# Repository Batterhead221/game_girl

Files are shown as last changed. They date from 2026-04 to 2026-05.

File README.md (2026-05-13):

# game_girl

GAME GIRL is a custom ESP32-S3 handheld mini-arcade built around a monochrome OLED display, rotary encoder controls, button input, buzzer audio, and battery support. AKA a handheld controlable tamagotchi like digital pet that I made for my niece.

## Features
- Custom PCB designed in KiCad
- ESP32-S3 based handheld platform
- 128x64 I2C OLED display
- Rotary encoder + push switch input
- Main action button
- Active buzzer audio
- Soft sleep mode
- Original mini-games:
  - Dress Up
  - Pocket Pet

## Hardware
- ESP32-S3 module
- 128x64 OLED
- Rotary encoder
- Pushbutton
- Active buzzer with transistor driver
- Single-cell LiPo support

## Firmware
The firmware is written in Arduino/C++ and organized as a menu-driven state machine. The device includes a launcher menu, game states, UI rendering, sound feedback, and long-press sleep behavior for handheld use.

## Engineering Highlights
- Built a complete handheld embedded system from schematic to assembled PCB
- Designed a compact display-based UI for limited-resolution hardware
- Implemented encoder and button-driven navigation across multiple games
- Added battery-friendly soft sleep behavior
- Debugged hardware bring-up issues including buzzer driver behavior and real-world encoder handling

## Challenges and Fixes
One of the main bring-up issues was the buzzer driver stage. The buzzer itself tested correctly, but in-circuit debugging showed the low-side transistor stage was not pulling the buzzer node low enough. After tracing the behavior with meter checks and signal testing, the emitter path was corrected to achieve proper switching. I also iterated on encoder handling to make gameplay and menu control more usable with a mechanical rotary input.

## Status
Working prototype. Core hardware and firmware are functional, with several improvements identified for a future board revision.

Next rev will be more compact, "kid friendly" and "prettier"

Designed & Engineered by Brandon Shelly

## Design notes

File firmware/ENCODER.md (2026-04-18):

#include <Wire.h>
#include <LiquidCrystal_I2C.h>

LiquidCrystal_I2C lcd(0x27, 16, 2);

const int ENC_A  = 1;   // D0
const int ENC_B  = 2;   // D1
const int ENC_SW = 3;   // D2

int count = 0;
int lastAState = HIGH;
unsigned long lastStepTime = 0;
const unsigned long stepDelayMs = 3;

void drawScreen() {
  lcd.clear();
  lcd.setCursor(0, 0);
  lcd.print("GAME_GIRL");
  lcd.setCursor(0, 1);
  lcd.print("COUNT: ");
  lcd.print(count);
}

void setup() {
  Wire.begin(5, 6);   // SDA=D4, SCL=D5
  lcd.init();
  lcd.backlight();

  pinMode(ENC_A, INPUT_PULLUP);
  pinMode(ENC_B, INPUT_PULLUP);
  pinMode(ENC_SW, INPUT_PULLUP);

  lastAState = digitalRead(ENC_A);
  drawScreen();
}

void loop() {
  int aState = digitalRead(ENC_A);

  if (aState != lastAState) {
    if (millis() - lastStepTime > stepDelayMs) {
      if (aState == LOW) {
        if (digitalRead(ENC_B) != aState) {
          count++;
        } else {
          count--;
        }
        drawScreen();
        lastStepTime = millis();
      }
    }
  }

  lastAState = aState;

  if (digitalRead(ENC_SW) == LOW) {
    lcd.clear();
    lcd.setCursor(0, 0);
    lcd.print("BUTTON PRESS");
    lcd.setCursor(0, 1);
    lcd.print("COUNT: ");
    lcd.print(count);
    delay(250);

    while (digitalRead(ENC_SW) == LOW) {
      delay(10);
    }

    drawScreen();
  }
}

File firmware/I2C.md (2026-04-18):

#include <Wire.h>

void setup() {
  Serial.begin(115200);
  delay(2000);

  Serial.println();
  Serial.println("BOOT OK");
  Serial.println("STARTING I2C SCAN");

  Wire.begin(5, 6);   // SDA=D4, SCL=D5 on XIAO ESP32S3
  delay(100);
}

void loop() {
  byte error, address;
  int count = 0;

  Serial.println("SCANNING...");

  for (address = 1; address < 127; address++) {
    Wire.beginTransmission(address);
    error = Wire.endTransmission();

    if (error == 0) {
      Serial.print("FOUND I2C DEVICE AT 0X");
      if (address < 16) Serial.print("0");
      Serial.println(address, HEX);
      count++;
    }
  }

  if (count == 0) {
    Serial.println("NO I2C DEVICES FOUND");
  } else {
    Serial.println("SCAN DONE");
  }

  Serial.println("-----");
  delay(3000);
}

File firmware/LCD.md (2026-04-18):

#include <Wire.h>
#include <LiquidCrystal_I2C.h>

LiquidCrystal_I2C lcd(0x27, 16, 2);

void setup() {
  Wire.begin(5, 6);   // SDA=D4, SCL=D5 on XIAO ESP32S3
  lcd.init();
  lcd.backlight();

  lcd.clear();
  lcd.setCursor(0, 0);
  lcd.print("GAME_GIRL");

  lcd.setCursor(0, 1);
  lcd.print("PRESS TO PLAY");
}

void loop() {
}

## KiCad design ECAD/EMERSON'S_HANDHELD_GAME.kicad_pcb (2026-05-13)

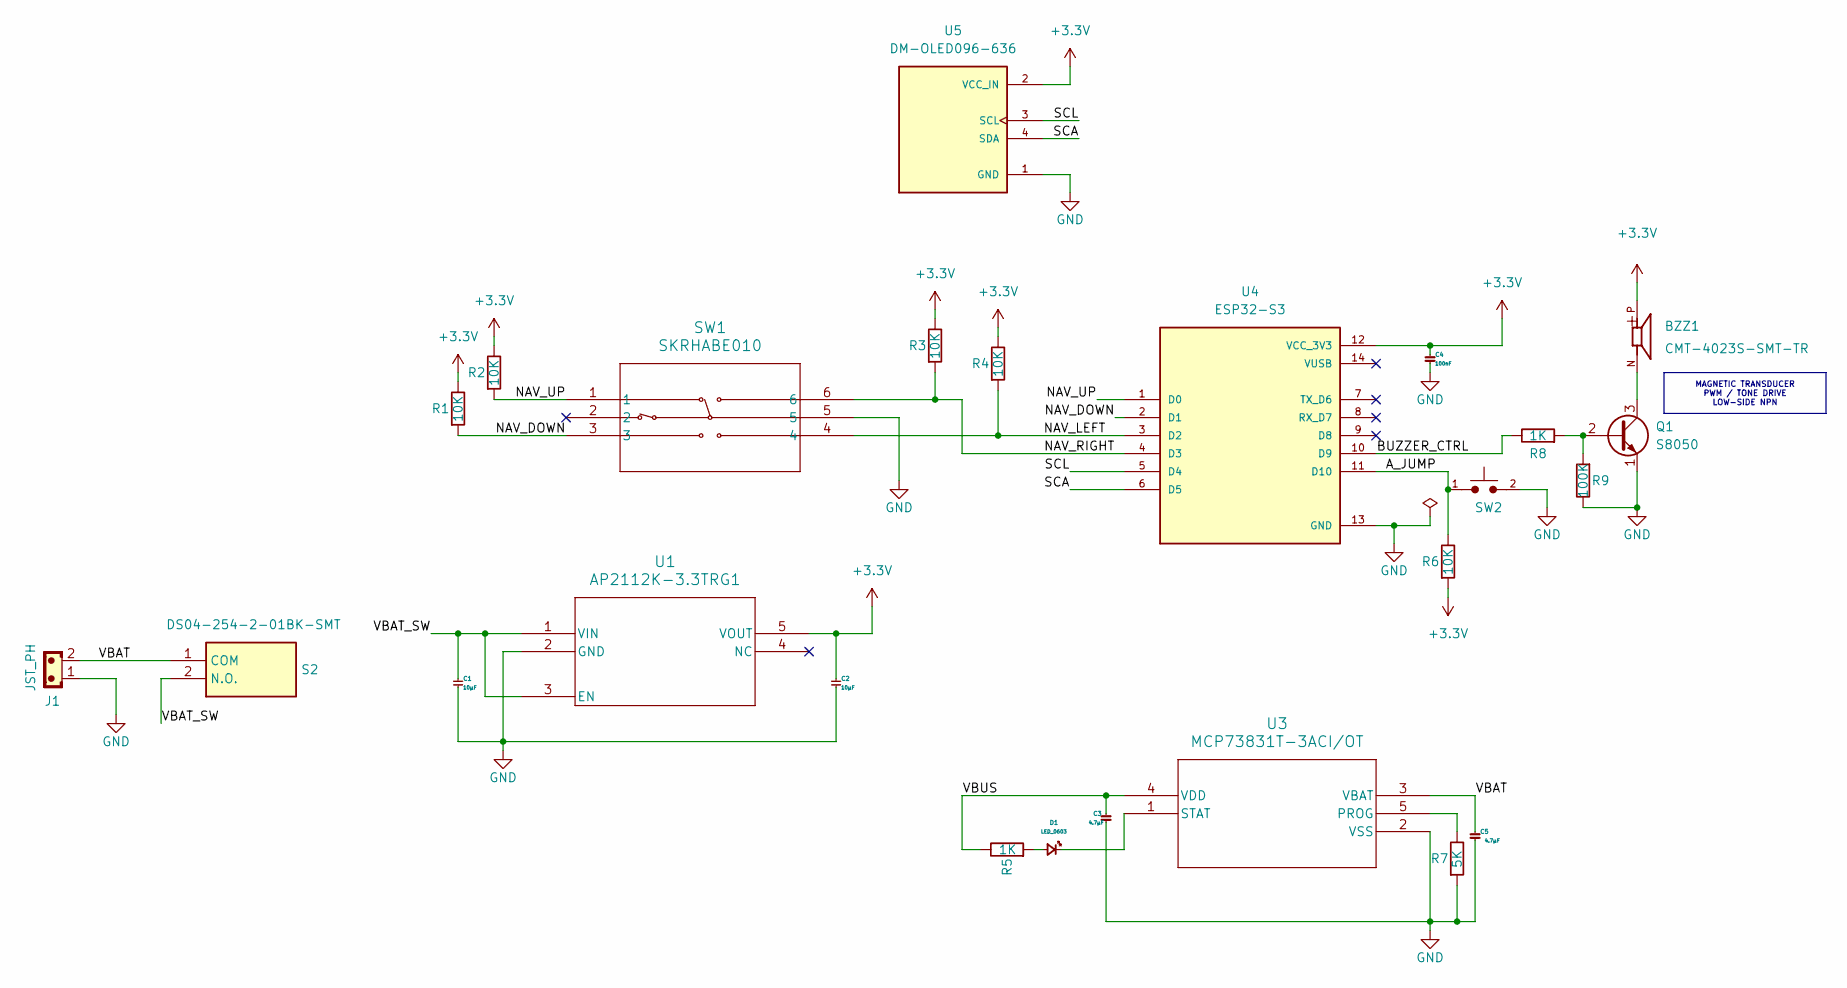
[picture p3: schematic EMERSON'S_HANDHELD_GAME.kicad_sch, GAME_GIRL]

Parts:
BZZ1: CMT-4023S-SMT-TR; CUI_CMT-4023S-SMT-TR; PARTREV 1.0
C1, C2: 10µF; C_0603_1608Metric
C3, C5: 4.7µF; C_0805_2012Metric; MPN C3216X5R1V226M160AC
C4: 100nF; C_0603_1608Metric
D1: LED_0603; LED_0603_1608Metric
J1: JST_PH; JST_PH_S2B-PH-K_1x02_P2.00mm_Horizontal
Q1: S8050; TO-92
R1, R2, R3, R4, R6: 10K; R_0603_1608Metric
R5, R8: 1K; R_0603_1608Metric
R7: 5K; R_0603_1608Metric
R9: 100K; R_0603_1608Metric
S2: DS04-254-2-01BK-SMT; Mouser Part Number 490-DS04254201BK-SMT
SW1: SKRHABE010
SW2: BUTTON; OMRON_SW_THT
U1: AP2112K-3.3TRG1; SOT-23-5
U3: MCP73831T-3ACI/OT; SOT-23-5_MC_MCH
U4: ESP32-S3; ESP32-S3_PADS_REMOVED; PARTREV 23/05/2022
U5: DM-OLED096-636; OLED; PARTREV 2018-09-10

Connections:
+3.3V: BZZ1.P, C2.2, C4.2, R1.2, R2.2, R3.2, R4.2, R6.1, U1.5 (VOUT), U4.12 (VCC_3V3), U5.2 (VCC_IN)
/A_JUMP: R6.2, SW2.1, U4.11 (D10)
/BUZZER_CTRL: R8.2, U4.10 (D9)
/NAV_DOWN: R1.1, SW1.3, U4.2 (D1)
/NAV_LEFT: R4.1, SW1.4, U4.3 (D2)
/NAV_RIGHT: R3.1, SW1.6, U4.4 (D3)
/NAV_UP: R2.1, SW1.1, U4.1 (D0)
/SCA: U4.6 (D5), U5.4 (SDA)
/SCL: U4.5 (D4), U5.3 (SCL)
/VBAT: C5.2, J1.2, S2.1 (COM), U3.3 (VBAT)
/VBAT_SW: C1.2, S2.2 (N.O.), U1.1 (VIN), U1.3 (EN)
/VBUS: C3.2, R5.2, U3.4 (VDD)
GND: C1.1, C2.1, C3.1, C4.1, C5.1, J1.1, Q1.1 (E), R7.1, R9.2, SW1.5, SW2.2, U1.2 (GND), U3.2 (VSS), U4.13 (GND), U5.1 (GND)
unnamed: D1.2 (A), R5.1
unnamed: D1.1 (K), U3.1 (STAT)
unnamed: Q1.2 (B), R8.1, R9.1
unnamed: BZZ1.N, Q1.3 (C)
unnamed: R7.2, U3.5 (PROG)

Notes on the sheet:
MAGNETIC TRANSDUCER PWM / TONE DRIVE LOW-SIDE NPN

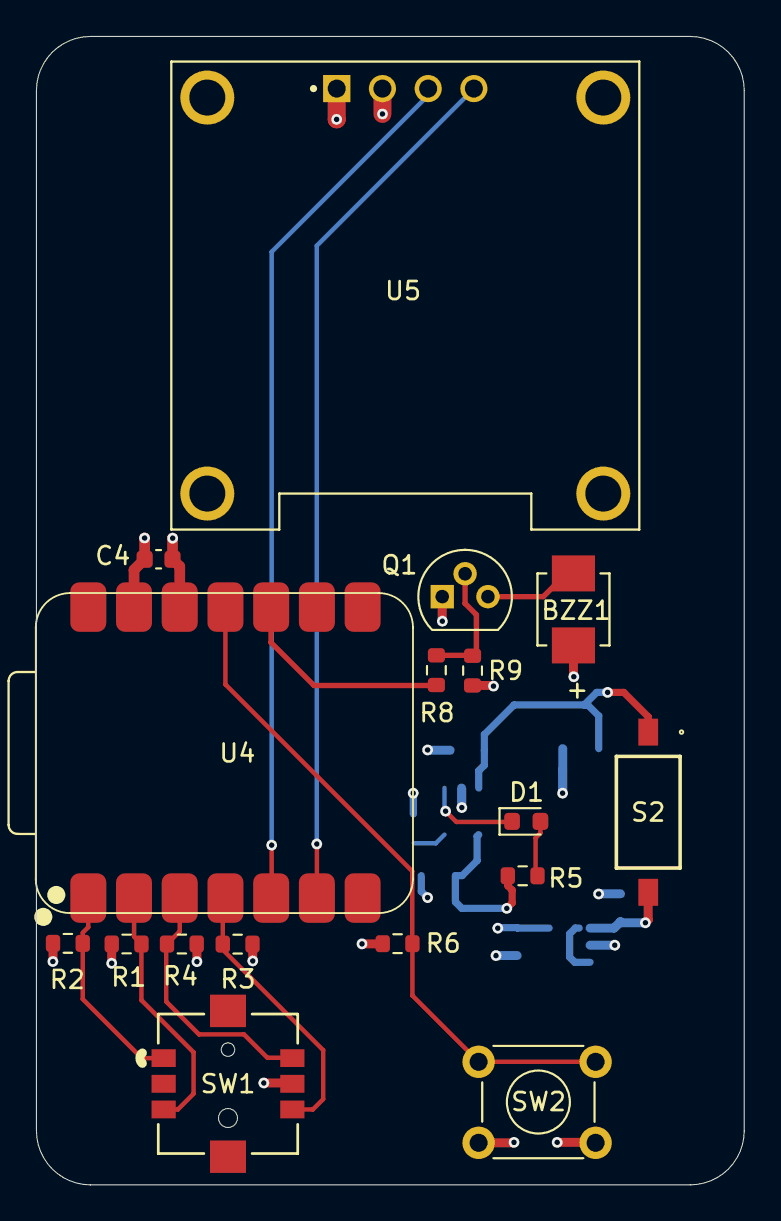
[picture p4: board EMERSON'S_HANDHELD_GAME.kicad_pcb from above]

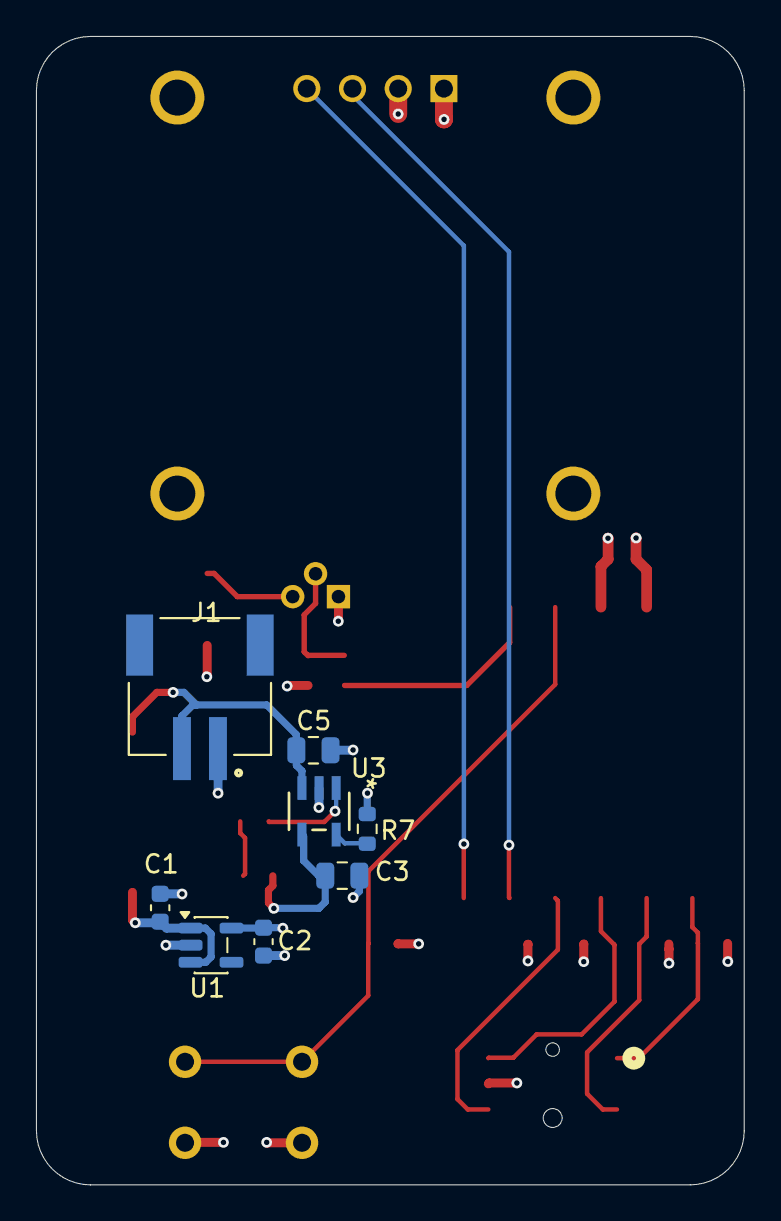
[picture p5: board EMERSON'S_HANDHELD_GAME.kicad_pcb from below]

Board: 4 copper layers, 39.3 x 63.8 mm, 25 parts (8 on the bottom side), 18 nets.

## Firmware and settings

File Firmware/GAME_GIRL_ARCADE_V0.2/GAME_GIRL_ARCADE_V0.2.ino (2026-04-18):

#include <Arduino.h>
#include <Wire.h>
#include <Adafruit_GFX.h>
#include <Adafruit_SSD1306.h>
#include "esp_sleep.h"

// ======================================================
// XIAO pin compatibility for ESP32S3 Dev Module builds
// ======================================================
#ifndef D0
  #define D0 1
#endif
#ifndef D1
  #define D1 2
#endif
#ifndef D2
  #define D2 3
#endif
#ifndef D3
  #define D3 4
#endif
#ifndef D4
  #define D4 5
#endif
#ifndef D5
  #define D5 6
#endif
#ifndef D8
  #define D8 7
#endif

// ======================================================
// PIN MAP
// ======================================================
static const int PIN_ENC_CLK    = D0;
static const int PIN_ENC_DT     = D1;
static const int PIN_ENC_SW     = D2;
static const int PIN_BTN_MAIN   = D3;
static const int PIN_OLED_SDA   = D4;
static const int PIN_OLED_SCL   = D5;
static const int PIN_BUZZER     = D8;

// ======================================================
// OLED
// ======================================================
#define SCREEN_WIDTH 128
#define SCREEN_HEIGHT 64
#define OLED_ADDR 0x3C

Adafruit_SSD1306 display(SCREEN_WIDTH, SCREEN_HEIGHT, &Wire, -1);

// ======================================================
// BUTTONS
// ======================================================
struct Button {
  int pin;
  bool stableState;
  bool lastReading;
  unsigned long lastDebounceTime;
  const unsigned long debounceDelay = 25;
  bool pressedEvent;
};

Button btnMain { PIN_BTN_MAIN, HIGH, HIGH, 0, 25, false };
Button btnEnc  { PIN_ENC_SW,   HIGH, HIGH, 0, 25, false };

// ======================================================
// ENCODER
// Relative left/right only
// ======================================================
volatile int encoderSteps = 0;
int lastEncoded = 0;
int encoderAcc = 0;
unsigned long lastEncoderTransitionUs = 0;
const unsigned long ENCODER_FILTER_US = 400;

// ======================================================
// SOFT POWER / SLEEP
// ======================================================
unsigned long powerHoldStart = 0;
bool powerHoldActive = false;
const unsigned long POWER_HOLD_MS = 3000;

// ======================================================
// BUZZER
// ======================================================
void buzzerOn()  { digitalWrite(PIN_BUZZER, HIGH); }
void buzzerOff() { digitalWrite(PIN_BUZZER, LOW); }

void beep(uint16_t durationMs) {
  buzzerOn();
  delay(durationMs);
  buzzerOff();
}

void chirp(uint16_t onMs, uint16_t offMs, uint8_t count) {
  for (uint8_t i = 0; i < count; i++) {
    buzzerOn();
    delay(onMs);
    buzzerOff();
    if (i < count - 1) delay(offMs);
  }
}

void tickSound()    { beep(3); }
void selectSound()  { beep(5); }
void happySound()   { chirp(4, 8, 2); }
void sparkleSound() { chirp(4, 6, 3); }

// ======================================================
// APP STATES
// ======================================================
enum AppState {
  STATE_SPLASH,
  STATE_HOME,
  STATE_DRESSUP,
  STATE_DRESSUP_FINISH,
  STATE_CATCH,
  STATE_CATCH_GAME_OVER,
  STATE_PET,
  STATE_PET_MENU
};

AppState appState = STATE_SPLASH;

// ======================================================
// HOME MENU
// ======================================================
const char* homeItems[] = {
  "DRESS UP",
  "CATCH STARS",
  "POCKET PET"
};
const int HOME_COUNT = sizeof(homeItems) / sizeof(homeItems[0]);
int homeIndex = 0;

// ======================================================
// DRESS UP DATA
// ======================================================
enum Category {
  CAT_FACE,
  CAT_HAIR,
  CAT_OUTFIT,
  CAT_ACCESSORY,
  CAT_PET,
  CAT_BACKGROUND,
  CAT_COUNT
};

const char* categoryNames[CAT_COUNT] = {
  "FACE",
  "HAIR",
  "OUTFIT",
  "ACCESSORY",
  "PET",
  "BACKGROUND"
};

const int FACE_COUNT = 3;
const int HAIR_COUNT = 4;
const int OUTFIT_COUNT = 4;
const int ACCESSORY_COUNT = 4;
const int PET_COUNT = 4;
const int BG_COUNT = 4;

int selectedFace = 0;
int selectedHair = 0;
int selectedOutfit = 0;
int selectedAccessory = 0;
int selectedPet = 0;
int selectedBg = 0;

Category currentCategory = CAT_FACE;

const char* finishItems[] = {
  "BACK TO MENU",
  "RANDOM LOOK"
};
const int FINISH_COUNT = 2;
int finishIndex = 0;

// ======================================================
// CATCH STARS
// ======================================================
int basketX = 52;
const int basketY = 55;
const int basketW = 20;
const int basketH = 6;

int starX = 40;
int starY = 8;
int starVX = 0;
int scoreCatch = 0;
int missesCatch = 0;
const int maxMissesCatch = 3;
unsigned long lastCatchTick = 0;
const unsigned long catchTickMs = 40;

bool magnetActive = false;
unsigned long magnetStart = 0;
const unsigned long magnetMs = 350;

// ======================================================
// POCKET PET
// ======================================================
int petX = 56;
int petY = 46;
int petVY = 0;
bool petOnGround = true;
bool petFacingRight = true;

int petHunger = 2;
int petHappy  = 4;
int petEnergy = 4;

unsigned long lastPetTick = 0;
unsigned long lastNeedTick = 0;
const unsigned long petTickMs = 30;
const unsigned long petNeedMs = 6000;

const char* petMenuItems[] = {
  "FEED",
  "PET",
  "NAP",
  "PLAY",
  "BACK"
};
const int PET_MENU_COUNT = 5;
int petMenuIndex = 0;

bool petBlink = false;
unsigned long lastBlinkMs = 0;

bool showHeart = false;
unsigned long heartStartMs = 0;
const unsigned long heartMs = 700;

bool showZzz = false;
unsigned long zzzStartMs = 0;
const unsigned long zzzMs = 1200;

int ballX = 102;
int ballY = 54;
int ballVX = 0;

// ======================================================
// HELPERS
// ======================================================
void resetPressedEvent(Button &b) {
  b.pressedEvent = false;
}

void updateButton(Button &b) {
  bool reading = digitalRead(b.pin);

  if (reading != b.lastReading) {
    b.lastDebounceTime = millis();
  }

  if ((millis() - b.lastDebounceTime) > b.debounceDelay) {
    if (reading != b.stableState) {
      b.stableState = reading;
      if (b.stableState == LOW) {
        b.pressedEvent = true;
      }
    }
  }

  b.lastReading = reading;
}

void updateEncoder() {
  int msb = digitalRead(PIN_ENC_CLK);
  int lsb = digitalRead(PIN_ENC_DT);

  int encoded = (msb << 1) | lsb;
  if (encoded == lastEncoded) return;

  unsigned long nowUs = micros();
  if (nowUs - lastEncoderTransitionUs < ENCODER_FILTER_US) {
    return;
  }
  lastEncoderTransitionUs = nowUs;

  int sum = (lastEncoded << 2) | encoded;
  int step = 0;

  // If direction is backwards, swap +1 and -1
  if (sum == 0b1101 || sum == 0b0100 || sum == 0b0010 || sum == 0b1011) {
    step = +1;
  } else if (sum == 0b1110 || sum == 0b0111 || sum == 0b0001 || sum == 0b1000) {
    step = -1;
  } else {
    lastEncoded = encoded;
    return;
  }

  if ((encoderAcc > 0 && step < 0) || (encoderAcc < 0 && step > 0)) {
    encoderAcc = 0;
  }

  encoderAcc += step;

  if (encoderAcc >= 2) {
    encoderSteps++;
    encoderAcc = 0;
  } else if (encoderAcc <= -2) {
    encoderSteps--;
    encoderAcc = 0;
  }

  lastEncoded = encoded;
}

int consumeEncoderDelta() {
  if (encoderSteps > 0) {
    encoderSteps--;
    return 1;
  }

  if (encoderSteps < 0) {
    encoderSteps++;
    return -1;
  }

  return 0;
}

int getEncoderStep() {
  int delta = consumeEncoderDelta();
  if (delta > 0) return 1;
  if (delta < 0) return -1;
  return 0;
}

void drawCenteredText(const String &text, int y, int textSize = 1) {
  display.setTextSize(textSize);
  display.setTextColor(SSD1306_WHITE);

  int16_t x1, y1;
  uint16_t w, h;
  display.getTextBounds(text, 0, y, &x1, &y1, &w, &h);

  int x = (SCREEN_WIDTH - w) / 2;
  display.setCursor(x, y);
  display.print(text);
}

void wrapValue(int &value, int maxCount) {
  if (value < 0) value = maxCount - 1;
  if (value >= maxCount) value = 0;
}

void drawFrame() {
  display.drawRoundRect(0, 0, SCREEN_WIDTH, SCREEN_HEIGHT, 6, SSD1306_WHITE);
}

void seedRandom() {
  randomSeed(micros());
}

// ======================================================
// SLEEP
// ======================================================
void enterSleep() {
  display.clearDisplay();
  drawCenteredText("SLEEPING...", 20, 1);
  drawCenteredText("GOOD NIGHT", 34, 1);
  display.display();

  beep(12);
  delay(80);

  display.ssd1306_command(SSD1306_DISPLAYOFF);
  delay(50);

  esp_sleep_enable_ext0_wakeup((gpio_num_t)PIN_BTN_MAIN, 0);
  esp_deep_sleep_start();
}

void handlePowerHold() {
  if (digitalRead(PIN_BTN_MAIN) == LOW) {
    if (!powerHoldActive) {
      powerHoldActive = true;
      powerHoldStart = millis();
    } else if (millis() - powerHoldStart >= POWER_HOLD_MS) {
      enterSleep();
    }
  } else {
    powerHoldActive = false;
  }
}

// ======================================================
// DRESS UP HELPERS
// ======================================================
void randomizeLook() {
  selectedFace = random(0, FACE_COUNT);
  selectedHair = random(0, HAIR_COUNT);
  selectedOutfit = random(0, OUTFIT_COUNT);
  selectedAccessory = random(0, ACCESSORY_COUNT);
  selectedPet = random(0, PET_COUNT);
  selectedBg = random(0, BG_COUNT);
}

void resetLook() {
  selectedFace = 0;
  selectedHair = 0;
  selectedOutfit = 0;
  selectedAccessory = 0;
  selectedPet = 0;
  selectedBg = 0;
  currentCategory = CAT_FACE;
  finishIndex = 0;
}

int getCurrentValue() {
  switch (currentCategory) {
    case CAT_FACE: return selectedFace;
    case CAT_HAIR: return selectedHair;
    case CAT_OUTFIT: return selectedOutfit;
    case CAT_ACCESSORY: return selectedAccessory;
    case CAT_PET: return selectedPet;
    case CAT_BACKGROUND: return selectedBg;
    default: return 0;
  }
}

void setCurrentValue(int value) {
  switch (currentCategory) {
    case CAT_FACE: selectedFace = value; wrapValue(selectedFace, FACE_COUNT); break;
    case CAT_HAIR: selectedHair = value; wrapValue(selectedHair, HAIR_COUNT); break;
    case CAT_OUTFIT: selectedOutfit = value; wrapValue(selectedOutfit, OUTFIT_COUNT); break;
    case CAT_ACCESSORY: selectedAccessory = value; wrapValue(selectedAccessory, ACCESSORY_COUNT); break;
    case CAT_PET: selectedPet = value; wrapValue(selectedPet, PET_COUNT); break;
    case CAT_BACKGROUND: selectedBg = value; wrapValue(selectedBg, BG_COUNT); break;
    default: break;
  }
}

// ======================================================
// CATCH HELPERS
// ======================================================
void resetCatchGame() {
  basketX = 52;
  starX = random(10, SCREEN_WIDTH - 10);
  starY = 10;
  starVX = 0;
  scoreCatch = 0;
  missesCatch = 0;
  magnetActive = false;
  magnetStart = 0;
  lastCatchTick = millis();
}

void respawnStar() {
  starX = random(8, SCREEN_WIDTH - 8);
  starY = 10;
  starVX = random(-1, 2);
}

bool starCaught() {
  int left = basketX;
  int right = basketX + basketW;
  int sLeft = starX - 2;
  int sRight = starX + 2;
  int sBottom = starY + 2;
  return (sBottom >= basketY) && (sRight >= left) && (sLeft <= right);
}

// ======================================================
// PET HELPERS
// ======================================================
void resetPetGame() {
  petX = 56;
  petY = 46;
  petVY = 0;
  petOnGround = true;
  petFacingRight = true;

  petHunger = 2;
  petHappy = 4;
  petEnergy = 4;

  petMenuIndex = 0;
  lastPetTick = millis();
  lastNeedTick = millis();
  lastBlinkMs = millis();
  petBlink = false;

  showHeart = false;
  showZzz = false;

  ballX = 102;
  ballY = 54;
  ballVX = 0;
}

void clampPetStats() {
  if (petHunger < 0) petHunger = 0;
  if (petHunger > 5) petHunger = 5;
  if (petHappy < 0) petHappy = 0;
  if (petHappy > 5) petHappy = 5;
  if (petEnergy < 0) petEnergy = 0;
  if (petEnergy > 5) petEnergy = 5;
}

void triggerHeart() {
  showHeart = true;
  heartStartMs = millis();
}

void triggerZzz() {
  showZzz = true;
  zzzStartMs = millis();
}

void doPetAction() {
  switch (petMenuIndex) {
    case 0: // FEED
      petHunger -= 2;
      petHappy += 1;
      happySound();
      break;

    case 1: // PET
      petHappy += 1;
      triggerHeart();
      tickSound();
      break;

    case 2: // NAP
      petEnergy += 2;
      petHappy += 1;
      triggerZzz();
      chirp(3, 10, 2);
      break;

    case 3: // PLAY
      petHappy += 2;
      petEnergy -= 1;
      petHunger += 1;
      ballVX = petFacingRight ? 3 : -3;
      sparkleSound();
      break;

    case 4: // BACK
      appState = STATE_PET;
      selectSound();
      return;
  }

  clampPetStats();
}

// ======================================================
// DRESS UP DRAWING
// ======================================================
void drawBackgroundStyle() {
  switch (selectedBg) {
    case 0:
      display.drawPixel(8, 10, SSD1306_WHITE);
      display.drawPixel(20, 18, SSD1306_WHITE);
      display.drawPixel(112, 12, SSD1306_WHITE);
      display.drawPixel(100, 22, SSD1306_WHITE);
      display.drawPixel(14, 52, SSD1306_WHITE);
      display.drawPixel(108, 50, SSD1306_WHITE);
      break;

    case 1:
      display.fillCircle(10, 12, 1, SSD1306_WHITE);
      display.fillCircle(13, 12, 1, SSD1306_WHITE);
      display.drawPixel(11, 14, SSD1306_WHITE);
      display.drawPixel(12, 14, SSD1306_WHITE);
      display.fillCircle(111, 14, 1, SSD1306_WHITE);
      display.fillCircle(114, 14, 1, SSD1306_WHITE);
      display.drawPixel(112, 16, SSD1306_WHITE);
      display.drawPixel(113, 16, SSD1306_WHITE);
      break;

    case 2:
      display.drawCircle(12, 12, 2, SSD1306_WHITE);
      display.drawPixel(12, 9, SSD1306_WHITE);
      display.drawPixel(12, 15, SSD1306_WHITE);
      display.drawPixel(9, 12, SSD1306_WHITE);
      display.drawPixel(15, 12, SSD1306_WHITE);

      display.drawCircle(114, 14, 2, SSD1306_WHITE);
      display.drawPixel(114, 11, SSD1306_WHITE);
      display.drawPixel(114, 17, SSD1306_WHITE);
      display.drawPixel(111, 14, SSD1306_WHITE);
      display.drawPixel(117, 14, SSD1306_WHITE);
      break;

    case 3:
      display.drawCircle(12, 14, 3, SSD1306_WHITE);
      display.drawCircle(16, 14, 3, SSD1306_WHITE);
      display.drawCircle(20, 14, 3, SSD1306_WHITE);

      display.drawCircle(103, 16, 3, SSD1306_WHITE);
      display.drawCircle(107, 16, 3, SSD1306_WHITE);
      display.drawCircle(111, 16, 3, SSD1306_WHITE);
      break;
  }
}

void drawFaceBase(int cx, int cy) {
  display.drawCircle(cx, cy, 10, SSD1306_WHITE);
}

void drawFaceFeatures(int cx, int cy) {
  switch (selectedFace) {
    case 0:
      display.fillCircle(cx - 3, cy - 2, 1, SSD1306_WHITE);
      display.fillCircle(cx + 3, cy - 2, 1, SSD1306_WHITE);
      display.drawPixel(cx - 2, cy + 3, SSD1306_WHITE);
      display.drawPixel(cx - 1, cy + 4, SSD1306_WHITE);
      display.drawPixel(cx,     cy + 4, SSD1306_WHITE);
      display.drawPixel(cx + 1, cy + 4, SSD1306_WHITE);
      display.drawPixel(cx + 2, cy + 3, SSD1306_WHITE);
      break;

    case 1:
      display.drawLine(cx - 4, cy - 2, cx - 2, cy - 2, SSD1306_WHITE);
      display.fillCircle(cx + 3, cy - 2, 1, SSD1306_WHITE);
      display.drawPixel(cx - 1, cy + 3, SSD1306_WHITE);
      display.drawPixel(cx,     cy + 4, SSD1306_WHITE);
      display.drawPixel(cx + 1, cy + 3, SSD1306_WHITE);
      break;

    case 2:
      display.drawLine(cx - 4, cy - 2, cx - 2, cy - 1, SSD1306_WHITE);
      display.drawLine(cx + 2, cy - 1, cx + 4, cy - 2, SSD1306_WHITE);
      display.drawLine(cx - 2, cy + 3, cx + 2, cy + 3, SSD1306_WHITE);
      break;
  }
}

void drawHair(int cx, int cy) {
  switch (selectedHair) {
    case 0:
      display.drawFastHLine(cx - 8, cy - 8, 16, SSD1306_WHITE);
      display.drawLine(cx - 8, cy - 8, cx - 9, cy + 2, SSD1306_WHITE);
      display.drawLine(cx + 8, cy - 8, cx + 9, cy + 2, SSD1306_WHITE);
      break;

    case 1:
      display.drawFastHLine(cx - 8, cy - 8, 16, SSD1306_WHITE);
      display.drawLine(cx - 8, cy - 8, cx - 7, cy + 1, SSD1306_WHITE);
      display.drawLine(cx + 8, cy - 8, cx + 7, cy + 1, SSD1306_WHITE);
      display.drawLine(cx + 8, cy - 3, cx + 13, cy - 6, SSD1306_WHITE);
      display.drawLine(cx + 13, cy - 6, cx + 12, cy, SSD1306_WHITE);
      break;

    case 2:
      display.drawFastHLine(cx - 8, cy - 8, 16, SSD1306_WHITE);
      display.drawLine(cx - 8, cy - 4, cx - 13, cy - 7, SSD1306_WHITE);
      display.drawLine(cx + 8, cy - 4, cx + 13, cy - 7, SSD1306_WHITE);
      display.drawLine(cx - 13, cy - 7, cx - 12, cy - 1, SSD1306_WHITE);
      display.drawLine(cx + 13, cy - 7, cx + 12, cy - 1, SSD1306_WHITE);
      break;

    case 3:
      display.drawFastHLine(cx - 8, cy - 8, 16, SSD1306_WHITE);
      display.drawLine(cx - 8, cy - 8, cx - 10, cy + 10, SSD1306_WHITE);
      display.drawLine(cx + 8, cy - 8, cx + 10, cy + 10, SSD1306_WHITE);
      break;
  }
}

void drawOutfit(int cx, int cy) {
  switch (selectedOutfit) {
    case 0:
      display.drawLine(cx, cy + 12, cx - 8, cy + 22, SSD1306_WHITE);
      display.drawLine(cx, cy + 12, cx + 8, cy + 22, SSD1306_WHITE);
      display.drawLine(cx - 8, cy + 22, cx + 8, cy + 22, SSD1306_WHITE);
      break;

    case 1:
      display.drawLine(cx, cy + 12, cx - 9, cy + 18, SSD1306_WHITE);
      display.drawLine(cx, cy + 12, cx + 9, cy + 18, SSD1306_WHITE);
      display.drawFastHLine(cx - 10, cy + 18, 20, SSD1306_WHITE);
      break;

    case 2:
      display.drawRect(cx - 6, cy + 12, 12, 10, SSD1306_WHITE);
      display.drawLine(cx - 4, cy + 12, cx - 4, cy + 9, SSD1306_WHITE);
      display.drawLine(cx + 4, cy + 12, cx + 4, cy + 9, SSD1306_WHITE);
      break;

    case 3:
      display.drawLine(cx, cy + 12, cx - 10, cy + 24, SSD1306_WHITE);
      display.drawLine(cx, cy + 12, cx + 10, cy + 24, SSD1306_WHITE);
      display.drawFastHLine(cx - 10, cy + 24, 20, SSD1306_WHITE);
      display.drawPixel(cx, cy + 18, SSD1306_WHITE);
      break;
  }

  display.drawLine(cx - 6, cy + 13, cx - 11, cy + 17, SSD1306_WHITE);
  display.drawLine(cx + 6, cy + 13, cx + 11, cy + 17, SSD1306_WHITE);
  display.drawLine(cx - 3, cy + 23, cx - 3, cy + 29, SSD1306_WHITE);
  display.drawLine(cx + 3, cy + 23, cx + 3, cy + 29, SSD1306_WHITE);
}

void drawAccessory(int cx, int cy) {
  switch (selectedAccessory) {
    case 0:
      display.drawPixel(cx + 7, cy - 10, SSD1306_WHITE);
      break;

    case 1:
      display.drawTriangle(cx - 2, cy - 11, cx - 7, cy - 9, cx - 2, cy - 7, SSD1306_WHITE);
      display.drawTriangle(cx + 2, cy - 11, cx + 7, cy - 9, cx + 2, cy - 7, SSD1306_WHITE);
      display.fillCircle(cx, cy - 9, 1, SSD1306_WHITE);
      break;

    case 2:
      display.drawLine(cx - 5, cy - 10, cx + 5, cy - 10, SSD1306_WHITE);
      display.drawLine(cx - 5, cy - 10, cx - 3, cy - 14, SSD1306_WHITE);
      display.drawLine(cx - 3, cy - 14, cx, cy - 10, SSD1306_WHITE);
      display.drawLine(cx, cy - 10, cx + 3, cy - 14, SSD1306_WHITE);
      display.drawLine(cx + 3, cy - 14, cx + 5, cy - 10, SSD1306_WHITE);
      break;

    case 3:
      display.drawCircle(cx + 8, cy - 9, 2, SSD1306_WHITE);
      display.drawPixel(cx + 8, cy - 12, SSD1306_WHITE);
      display.drawPixel(cx + 8, cy - 6, SSD1306_WHITE);
      display.drawPixel(cx + 5, cy - 9, SSD1306_WHITE);
      display.drawPixel(cx + 11, cy - 9, SSD1306_WHITE);
      break;
  }
}

void drawPetAccessory(int x, int y) {
  switch (selectedPet) {
    case 0:
      break;

    case 1:
      display.drawCircle(x, y, 5, SSD1306_WHITE);
      display.drawLine(x - 2, y - 5, x - 2, y - 11, SSD1306_WHITE);
      display.drawLine(x + 2, y - 5, x + 2, y - 11, SSD1306_WHITE);
      display.fillCircle(x - 2, y, 1, SSD1306_WHITE);
      display.fillCircle(x + 2, y, 1, SSD1306_WHITE);
      break;

    case 2:
      display.drawCircle(x, y, 5, SSD1306_WHITE);
      display.drawLine(x - 4, y - 3, x - 6, y - 7, SSD1306_WHITE);
      display.drawLine(x + 4, y - 3, x + 6, y - 7, SSD1306_WHITE);
      display.fillCircle(x - 2, y, 1, SSD1306_WHITE);
      display.fillCircle(x + 2, y, 1, SSD1306_WHITE);
      break;

    case 3:
      display.drawCircle(x, y, 5, SSD1306_WHITE);
      display.drawLine(x + 5, y, x + 8, y + 1, SSD1306_WHITE);
      display.fillCircle(x - 1, y - 1, 1, SSD1306_WHITE);
      display.fillCircle(x + 2, y - 1, 1, SSD1306_WHITE);
      break;
  }
}

void drawCharacterPreview() {
  int cx = 64;
  int cy = 24;

  drawBackgroundStyle();
  drawFaceBase(cx, cy);
  drawHair(cx, cy);
  drawFaceFeatures(cx, cy);
  drawAccessory(cx, cy);
  drawOutfit(cx, cy);

  if (selectedPet != 0) {
    drawPetAccessory(96, 48);
  }
}

// ======================================================
// PET DRAWING
// ======================================================
void drawPetStats() {
  display.setTextSize(1);
  display.setCursor(2, 2);
  display.print("H:");
  display.print(petHunger);

  display.setCursor(42, 2);
  display.print("P:");
  display.print(petHappy);

  display.setCursor(82, 2);
  display.print("E:");
  display.print(petEnergy);
}
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
void loop() {
  updateButton(btnMain);
  updateButton(btnEnc);
  updateEncoder();

  handlePowerHold();

  switch (appState) {
    case STATE_SPLASH:
      handleSplash();
      drawSplash();
      break;

    case STATE_HOME:
      handleHome();
      drawHome();
      break;

    case STATE_DRESSUP:
      handleDressUp();
      drawDressUp();
      break;

    case STATE_DRESSUP_FINISH:
      handleDressUpFinish();
      drawDressUpFinish();
      break;

    case STATE_CATCH:
      handleCatch();
      drawCatch();
      break;

    case STATE_CATCH_GAME_OVER:
      handleCatchGameOver();
      drawCatchGameOver();
      break;

    case STATE_PET:
      handlePet();
      drawPetRoom();
      break;

    case STATE_PET_MENU:
      handlePetMenu();
      drawPetMenu();
      break;
  }

  resetPressedEvent(btnMain);
  resetPressedEvent(btnEnc);

  delay(2);
}

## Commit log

2026-04-18 file path restructure
    [113991054.step, B2B-PH-K-S.step, Battery Detector v1.0.brd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]
2026-05-03 folder restructure
    [Battery Detector v1.0.brd, Battery Detector v1.0.sch, EMERSON'S_HANDHELD_GAME.kicad_pcb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]
2026-05-13 Revised repo
    [Battery Detector v1.0.brd, Battery Detector v1.0.sch, EMERSON'S_HANDHELD_GAME.kicad_pcb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]
